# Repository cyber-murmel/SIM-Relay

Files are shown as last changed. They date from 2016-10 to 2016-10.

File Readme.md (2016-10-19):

# SIM Relay
This is an approach of routing SIM card communication through a computer network. The project is based on [Ladyada's SIM reader](http://www.ladyada.net/make/simreader/)
## The Hardware
The printed circuit board is designed with surface mount parts only and measures 25.43x20.32 mm (1.00x0.80 inches). It only consist of a hex inverter, a crystal, some passives, a LED, the SIM card slot and pads to connect to an USB-UART converter. All passives and the LED are in a 0603 package.

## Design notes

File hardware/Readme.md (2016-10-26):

#Description
The board fullfills two tasks: Making the SIM card run by proving a clock and adapting the RX and TX signal of the UART to the one I/O line of the SIM card (transmit and receive to transceive).
The first part is done by connecting the in- and outputs of an inverter over a crystal that resonates with the desired frequency. This is stabilized by some passive components and then buffered by another inverter.
The transceiver part is done for the once direction by connecting the I/O line of the SIM card to the RX of the USB-UART converter. For the other direction, we pull up the I/O line by a resistor and connect the TX of the USB-UART converter through an inverter to a transistor, that can pull the line down (thereby the signal is double inverted).
Doing so, we prevent short circuiting that could occure if e.g. the SIM card pulls up and the USB-UART pulls down.
#Getting your own
I have the board uploaded to [OSH Park](https://oshpark.com/shared_projects/abhypSsD) if you want to order some.

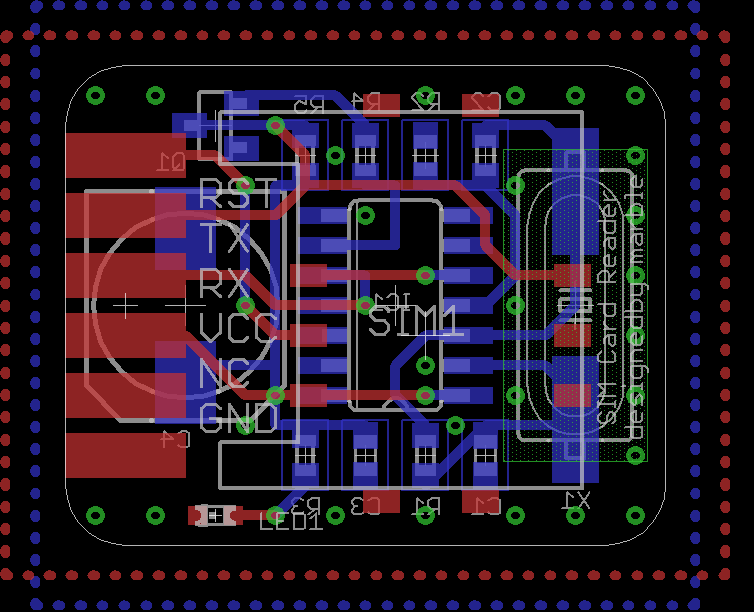
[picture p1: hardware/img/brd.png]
Board

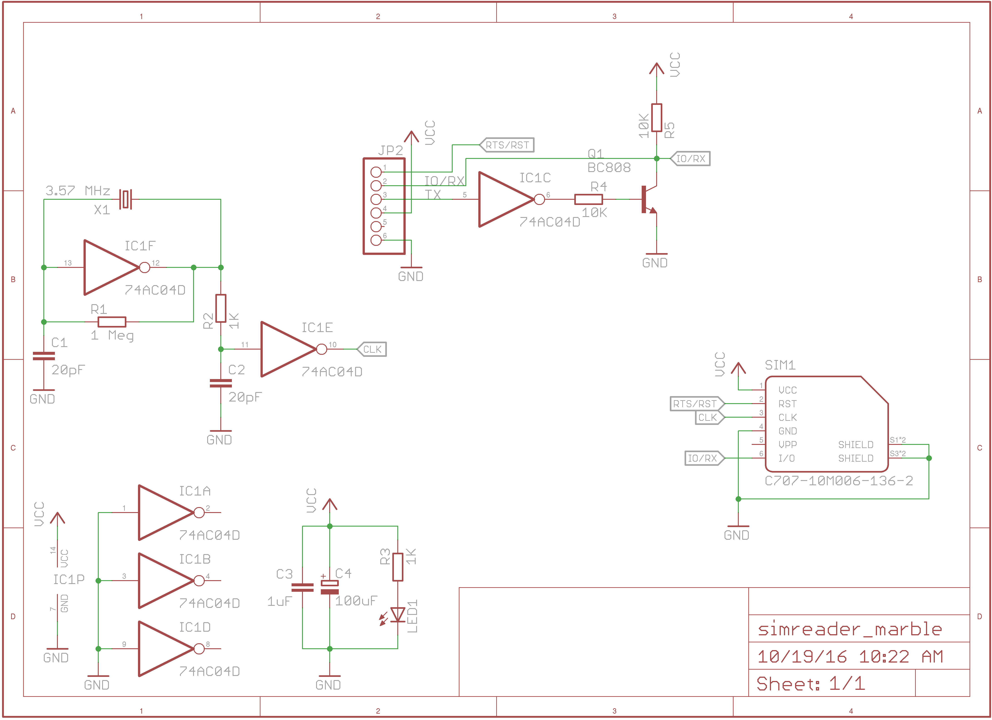
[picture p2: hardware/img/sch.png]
Schematic


|Part(s) |Value |
|---|---|
| C1, C2 | according to crystal (e.g. 15pF) |
| C3 | 1uF |
| C4 | 100uF |
| IC1 | 74AC04D |
| Q1 | NPN SOT23 BEC (e.g. MMBT2222A) |
| R1 | 1 Meg |
| R2, R3 | 1K |
| R4, R5 | 10K |
| SIM1| C707-10M006-136-2 |
| X1 | 3.686 MHz|

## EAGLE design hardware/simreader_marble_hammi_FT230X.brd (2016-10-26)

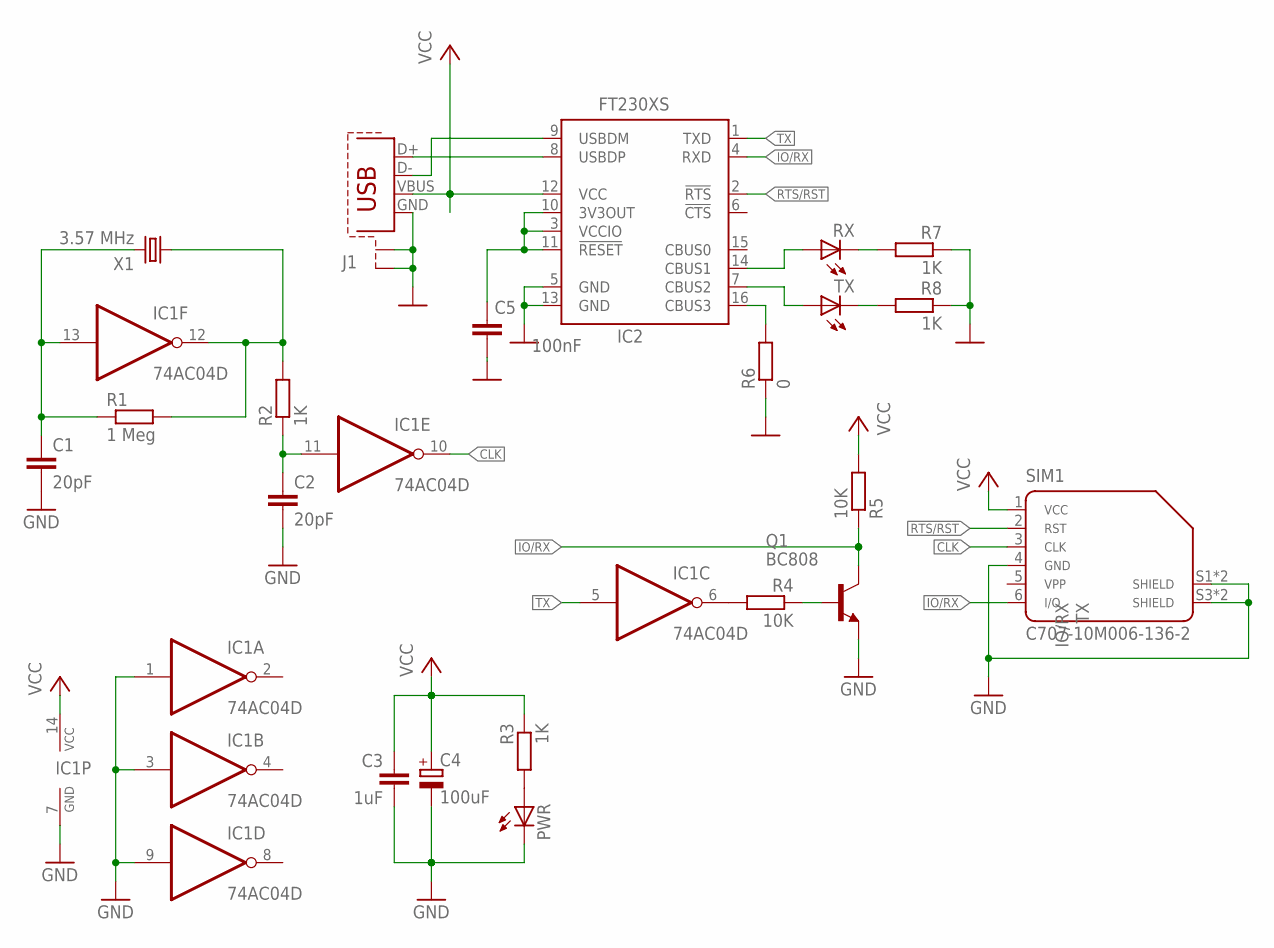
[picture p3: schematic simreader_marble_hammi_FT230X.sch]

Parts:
C1, C2: 20pF; C0603
C3: 1uF; C0603
C4: 100uF; 140CLH-0810
C5: 100nF; C0603
IC1: 74AC04D; SO14
IC2: FT230XS; SSOP-16
J1: USB-SHIELD-A-H; USB-A-H
PWR: LEDCHIPLED_0603; CHIPLED_0603
Q1: BC808; SOT23-BEC
R1: 1 Meg; R0603
R2, R3, R7, R8: 1K; R0603
R4, R5: 10K; R0603
R6: 0; R0603
RX: LEDCHIPLED_0603; CHIPLED_0603
SIM1: C707-10M006-136-2; C707_10M006_136_2
TX: LEDCHIPLED_0603; CHIPLED_0603
X1: 3.57 MHz; HC49UP

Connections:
CLK: IC1.10 (O), SIM1.3
GND: C1.2, C2.2, C3.2, C4.-, C5.2, IC1.1 (I), IC1.3 (I), IC1.7 (GND), IC1.9 (I), IC2.5 (GND), IC2.13 (GND), J1.GND, J1.GND2 (S1), J1.GND3 (S2), PWR.C, Q1.E, R6.1, R7.1, R8.1, SIM1.4, SIM1.S1, SIM1.S2 (S1), SIM1.S3 (S2), SIM1.S4 (S2)
IO/RX: IC2.4 (RXD), Q1.C, R5.1, SIM1.6
unnamed: C1.1, IC1.13 (I), R1.1, X1.2
unnamed: IC1.12 (O), R1.2, R2.2, X1.1
unnamed: C2.1, IC1.11 (I), R2.1
unnamed: IC1.6 (O), R4.2
unnamed: Q1.B, R4.1
unnamed: PWR.A, R3.2
unnamed: IC2.9 (USBDM), J1.D-
unnamed: IC2.8 (USBDP), J1.D+
unnamed: C5.1, IC2.3 (VCCIO), IC2.10 (3V3OUT), IC2.11 (!RESET)
unnamed: IC2.16 (CBUS3), R6.2
unnamed: IC2.14 (CBUS1), RX.A
unnamed: IC2.7 (CBUS2), TX.A
unnamed: R7.2, RX.C
unnamed: R8.2, TX.C
RTS/RST: IC2.2 (!RTS), SIM1.2
TX: IC1.5 (I), IC2.1 (TXD)
VCC: C3.1, C4.+, IC1.14 (VCC), IC2.12 (VCC), J1.VBUS, R3.1, R5.2, SIM1.1

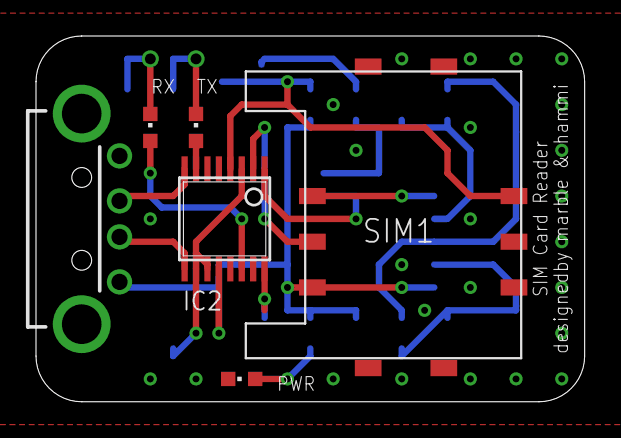
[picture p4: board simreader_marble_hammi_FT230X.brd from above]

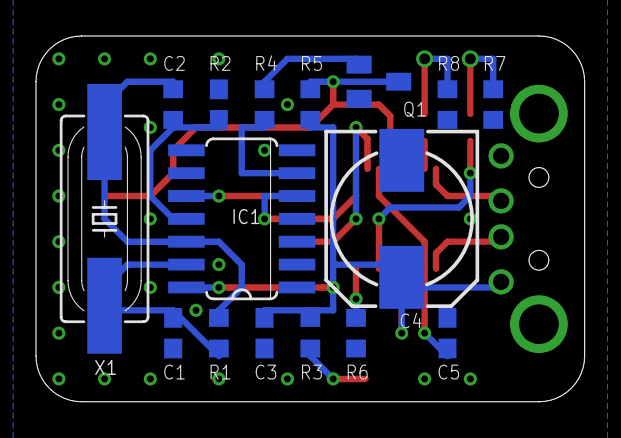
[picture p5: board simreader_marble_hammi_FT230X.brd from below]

Board: 2 copper layers, 30.5 x 20.3 mm, 22 parts (16 on the bottom side), 20 nets.

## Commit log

2016-10-14 added hardware files
    [sim_reader.brd, sim_reader.sch]
2016-10-19 redisgned. now compatible to most USB UART converters; very small
    [sim_reader.brd, sim_reader.sch]
2016-10-26 added boards with ftdi chip
    [simreader_marble_hammi_FT230X.brd, simreader_marble_hammi_FT230X.sch]
